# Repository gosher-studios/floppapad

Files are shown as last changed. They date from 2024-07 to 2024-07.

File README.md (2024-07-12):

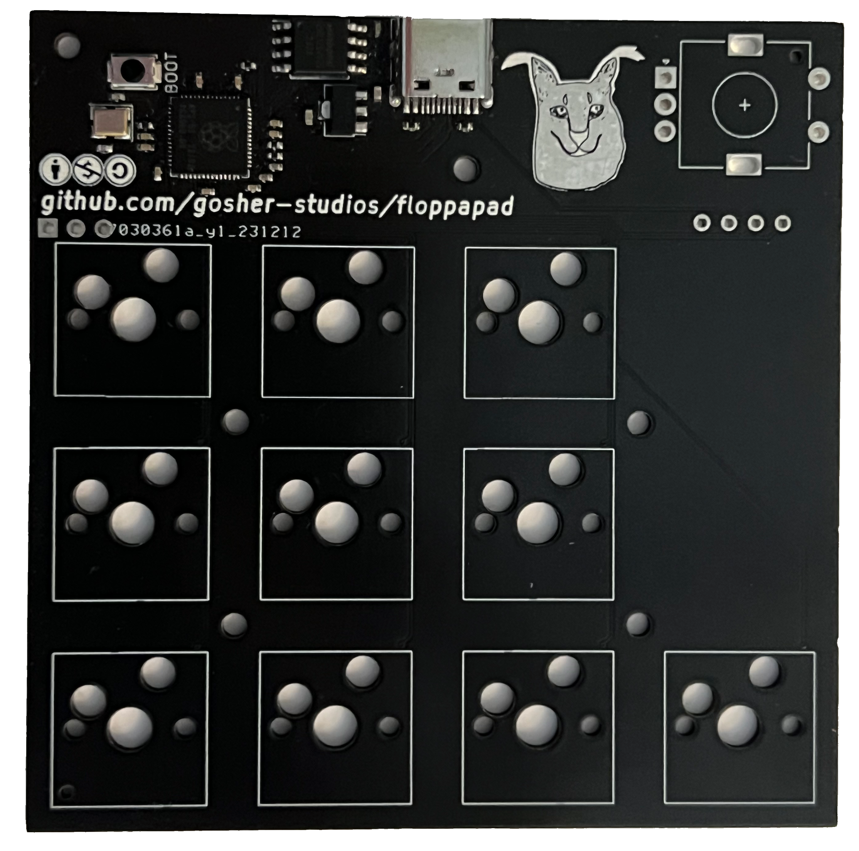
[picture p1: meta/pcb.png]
a black pcb with space for 10 mx switches, rotary encoder, oled display and usb-c port. there is a silver silhouette of a caracal in the top right


floppapad

silly little macropad

### features
- 10 hotswappable mx switches
- 128x32px oled display
- rotary encoder
- usb c
- scriptable and extensible firmware (coming soon)
- the silly caracal
<br/><br/><br/>

### Parts list

| Part | Quantity | Est. price | Example link |
|---|---|---|---|
| RP2040 | 1 | $1.01 | [LCSC](https://www.lcsc.com/product-detail/Microcontroller-Units-MCUs-MPUs-SOCs_Raspberry-Pi-RP2040_C2040.html) |
| USB-C port | 1 | $0.16 | [LCSC](https://www.lcsc.com/product-detail/USB-Connectors_Korean-Hroparts-Elec-TYPE-C-31-M-12_C165948.html) |
| SSD1306 128x32 OLED board | 1 | $4.00 | [42. Keebs](https://42keebs.eu/shop/parts/oled-display-0-91-128x32) |
| EC11 Rotary encoder | 1 | $2.00 | [LCSC](https://www.lcsc.com/product-detail/span-style-background-color-ff0-Rotary-span-Encoders_ALPSALPINE-EC11E183440C_C370986.html) |
| Kailh MX Hotswap sockets | 10 | $3.00 | [Mechboards](https://mechboards.co.uk/collections/components/products/kailh-hotswap-sockets) |
| MX Compatible switches | 10 | ~$10.00 | bring your favourite ✨ |
| SOIC 208-mil SPI flash[^1] | 1 | $0.56 | [LCSC](https://www.lcsc.com/product-detail/NOR-FLASH_Winbond-Elec-W25Q128JVSIQ_C97521.html) |
| SMD3225 12MHz Crystal oscillator | 1 | $0.06 | [LCSC](https://www.lcsc.com/product-detail/Crystals_YXC-X322512MSB4SI_C9002.html) |
| 3.9x2.9mm SMD Switch | 1 | $0.11 | [LCSC](https://www.lcsc.com/product-detail/Tactile-Switches_ALPSALPINE-SKRKAEE020_C115357.html) |
| SOT-89 3.3v Voltage regulator | 1 | $0.05 | [LCSC](https://www.lcsc.com/product-detail/Linear-Voltage-Regulators-LDO_UMW-Youtai-Semiconductor-Co-Ltd-AMS1117-3-3_C347256.html) |
| 27.4Ω Resistors[^2] | 2 | < $0.00 | [LCSC](https://www.lcsc.com/product-detail/Chip-Resistor-Surface-Mount_UNI-ROYAL-Uniroyal-Elec-0402WGF274JTCE_C31439.html) |
| 1kΩ Resistors[^2] | 2 | < $0.00 | [LCSC](https://www.lcsc.com/product-detail/Chip-Resistor-Surface-Mount_UNI-ROYAL-Uniroyal-Elec-0402WGF1001TCE_C11702.html) |
| 5.1kΩ Resistors[^2] | 2 | < $0.00 | [LCSC](https://www.lcsc.com/product-detail/Chip-Resistor-Surface-Mount_UNI-ROYAL-Uniroyal-Elec-0402WGF5101TCE_C25905.html) |
| 27pF Capacitors[^2] | 2 | < $0.00 | [LCSC](https://www.lcsc.com/product-detail/Multilayer-Ceramic-Capacitors-MLCC-SMD-SMT_Samsung-Electro-Mechanics-CL05C270JB51PNC_C472451.html) |
| 100nF Capacitors[^2] | 10 | < $0.00 | [LCSC](https://www.lcsc.com/product-detail/Multilayer-Ceramic-Capacitors-MLCC-SMD-SMT_Samsung-Electro-Mechanics-CL05B104KO5NNNC_C1525.html) |
| 1uF Capacitors[^2] | 2 | < $0.00 | [LCSC](https://www.lcsc.com/product-detail/Multilayer-Ceramic-Capacitors-MLCC-SMD-SMT_Samsung-Electro-Mechanics-CL05A105KA5NQNC_C52923.html) |
| 10uF Capacitors[^2] | 2 | < $0.00 | [LCSC](https://www.lcsc.com/product-detail/Multilayer-Ceramic-Capacitors-MLCC-SMD-SMT_Samsung-Electro-Mechanics-CL05A106MQ5NUNC_C15525.html) |

[^1]: The firmware is ~36KB for a release build. We use 16MB flash.
[^2]: All resistors and capacitors are 0402.

### Credits

Brought to you by Alex T and Gosha T ❤️ \
This work is licensed under [Creative Commons BY-NC-SA 4.0](https://creativecommons.org/licenses/by-nc-sa/4.0/)



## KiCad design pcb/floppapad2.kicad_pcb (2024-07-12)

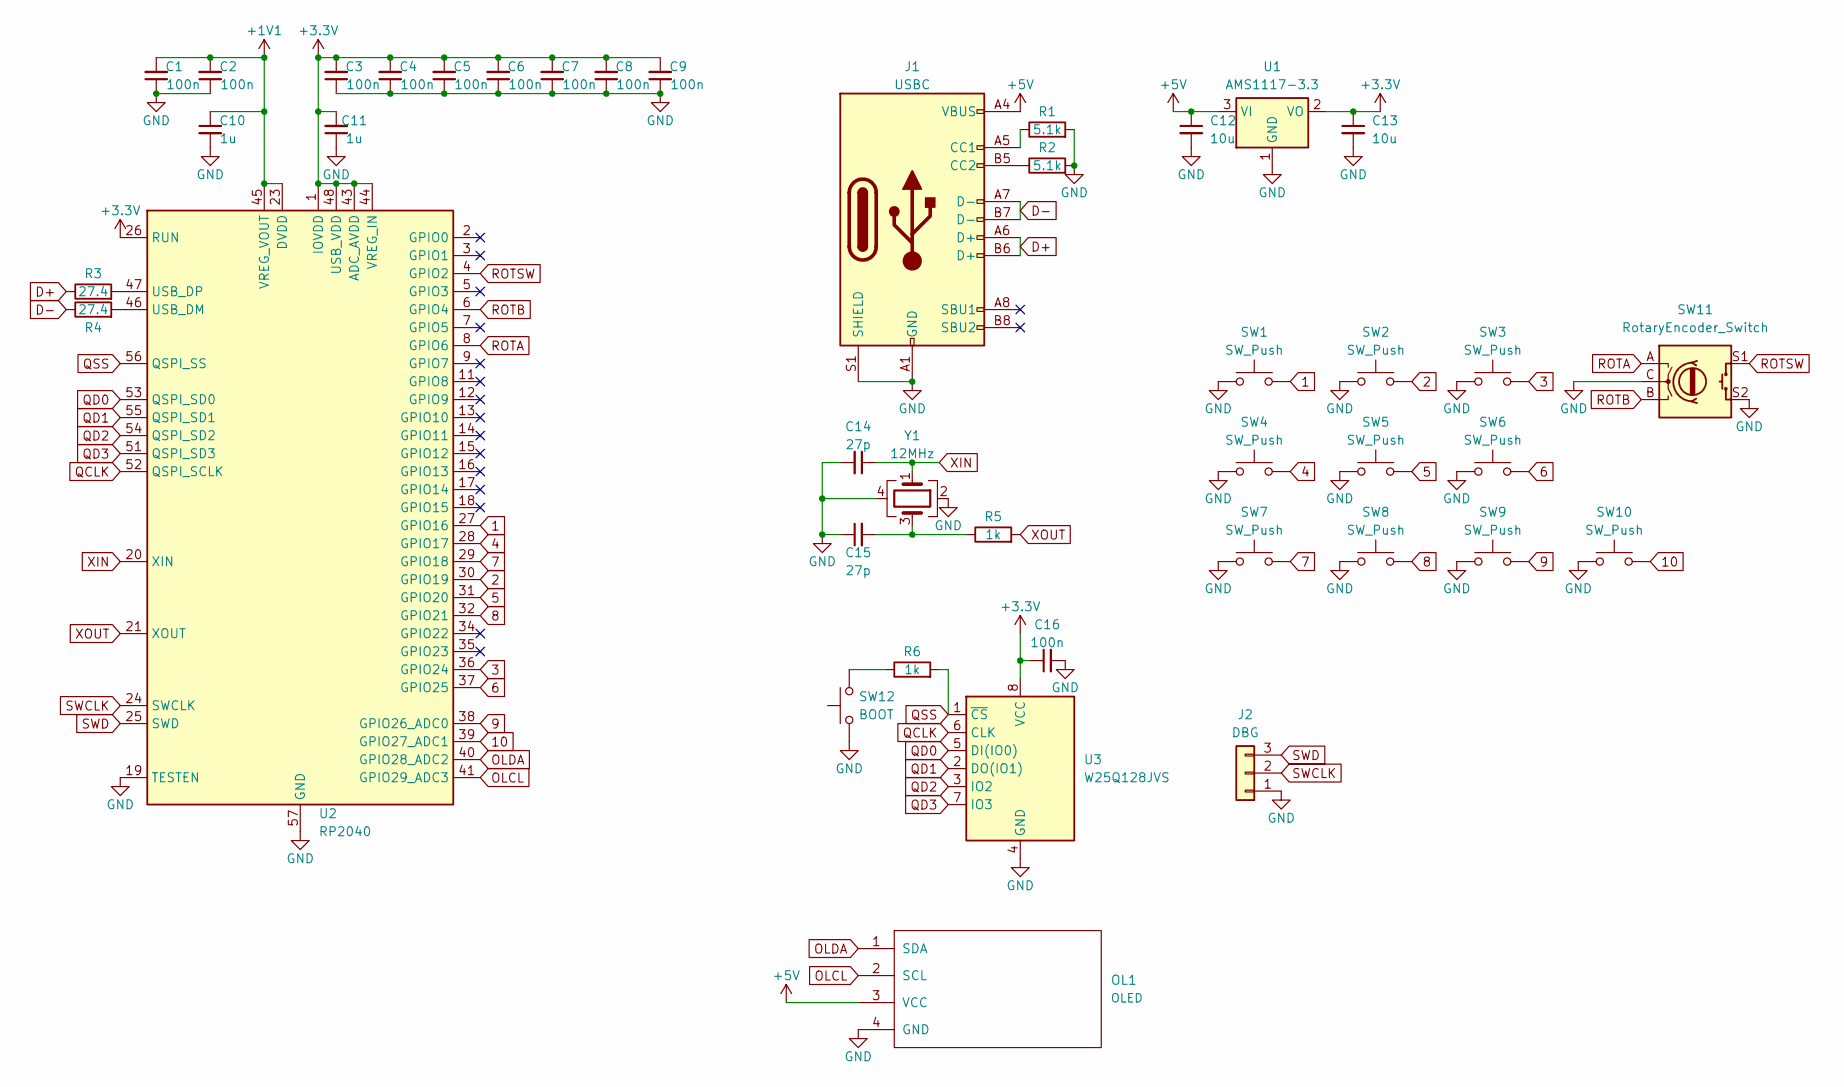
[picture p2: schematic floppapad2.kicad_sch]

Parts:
C1, C2, C3, C4, C5, C6, C7, C8, C9, C16: 100n; C_0402_1005Metric
C10, C11: 1u; C_0402_1005Metric
C12, C13: 10u; C_0402_1005Metric
C14, C15: 27p; C_0402_1005Metric
J1: USBC; USB_C_Receptacle_HRO_TYPE-C-31-M-12
J2: DBG; PinSocket_1x03_P2.54mm_Vertical
OL1: OLED; OLED_v2.1
R1, R2: 5.1k; R_0402_1005Metric
R3, R4: 27.4; R_0402_1005Metric
R5, R6: 1k; R_0402_1005Metric
SW1, SW2, SW3, SW4, SW5, SW6, SW7, SW8, SW9, SW10: SW_Push; SW_Hotswap_Kailh_MX_1.00u
SW11: RotaryEncoder_Switch; RotaryEncoder_Alps_EC11E-Switch_Vertical_H20mm
SW12: BOOT; SW_Push_SPST_NO_Alps_SKRK
U1: AMS1117-3.3; SOT-89-3
U2: RP2040; QFN-56-1EP_7x7mm_P0.4mm_EP3.2x3.2mm
U3: W25Q128JVS; SOIC-8_5.23x5.23mm_P1.27mm
Y1: 12MHz; Crystal_SMD_TXC_7M-4Pin_3.2x2.5mm

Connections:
1: SW1.2, U2.27 (GPIO16)
2: SW2.2, U2.30 (GPIO19)
3: SW3.2, U2.36 (GPIO24)
4: SW4.2, U2.28 (GPIO17)
5: SW5.2, U2.31 (GPIO20)
6: SW6.2, U2.37 (GPIO25)
7: SW7.2, U2.29 (GPIO18)
8: SW8.2, U2.32 (GPIO21)
9: SW9.2, U2.38 (GPIO26_ADC0)
10: SW10.2, U2.39 (GPIO27_ADC1)
+1V1: C1.2, C2.2, C10.1, U2.23 (DVDD), U2.45 (VREG_VOUT), U2.50 (DVDD)
+3.3V: C3.2, C4.2, C5.2, C6.2, C7.2, C8.2, C9.2, C11.2, C13.1, C16.1, U1.2 (VO), U2.1 (IOVDD), U2.10 (IOVDD), U2.22 (IOVDD), U2.26 (RUN), U2.33 (IOVDD), U2.42 (IOVDD), U2.43 (ADC_AVDD), U2.44 (VREG_IN), U2.48 (USB_VDD), U2.49 (IOVDD), U3.8 (VCC)
+5V: C12.1, J1.A4 (VBUS), J1.A9 (VBUS), J1.B4 (VBUS), J1.B9 (VBUS), OL1.3 (VCC), U1.3 (VI)
D+: J1.A6 (D+), J1.B6 (D+), R3.1
D-: J1.A7 (D-), J1.B7 (D-), R4.1
GND: C1.1, C2.1, C3.1, C4.1, C5.1, C6.1, C7.1, C8.1, C9.1, C10.2, C11.1, C12.2, C13.2, C14.2, C15.1, C16.2, J1.A1 (GND), J1.A12 (GND), J1.B1 (GND), J1.B12 (GND), J1.S1 (SHIELD), J2.1, OL1.4 (GND), R1.2, R2.2, SW1.1, SW2.1, SW3.1, SW4.1, SW5.1, SW6.1, SW7.1, SW8.1, SW9.1, SW10.1, SW11.C, SW11.S2, SW12.1, SW12.C, SW12.S2, U1.1 (GND), U2.19 (TESTEN), U2.57 (GND), U3.4 (GND), Y1.2, Y1.4; also elsewhere on the board
unnamed: C15.2, R5.1, Y1.3
unnamed: J1.A5 (CC1), R1.1
unnamed: J1.B5 (CC2), R2.1
unnamed: R6.1, SW12.2
unnamed: R4.2, U2.46 (USB_DM)
unnamed: R3.2, U2.47 (USB_DP)
OLCL: OL1.2 (SCL), U2.41 (GPIO29_ADC3)
OLDA: OL1.1 (SDA), U2.40 (GPIO28_ADC2)
QCLK: U2.52 (QSPI_SCLK), U3.6 (CLK)
QD0: U2.53 (QSPI_SD0), U3.5 (DI(IO0))
QD1: U2.55 (QSPI_SD1), U3.2 (DO(IO1))
QD2: U2.54 (QSPI_SD2), U3.3 (IO2)
QD3: U2.51 (QSPI_SD3), U3.7 (IO3)
QSS: R6.2, U2.56 (QSPI_SS), U3.1 (~CS)
ROTA: SW11.A, U2.8 (GPIO6)
ROTB: SW11.B, U2.6 (GPIO4)
ROTSW: SW11.S1, U2.4 (GPIO2)
SWCLK: J2.2, U2.24 (SWCLK); also elsewhere on the board
SWD: J2.3, U2.25 (SWD); also elsewhere on the board
XIN: C14.1, U2.20 (XIN), Y1.1
XOUT: R5.2, U2.21 (XOUT)

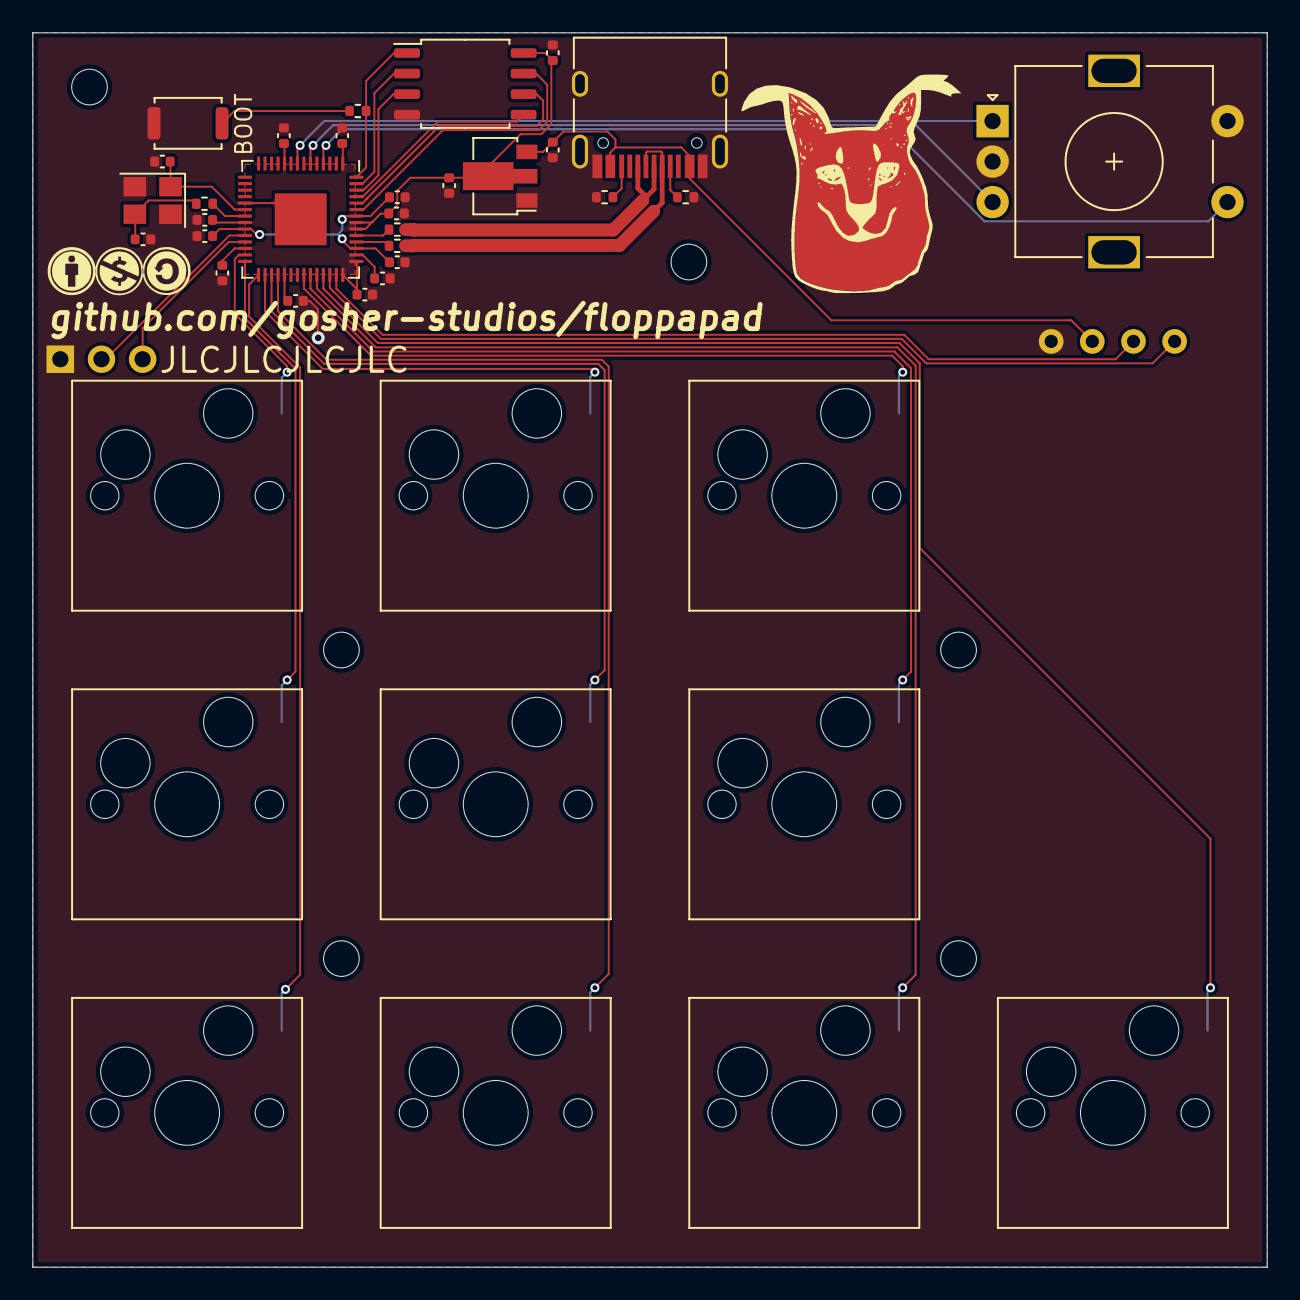
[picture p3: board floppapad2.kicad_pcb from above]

Board: 2 copper layers, 76.2 x 76.2 mm, 41 parts (0 on the bottom side), 37 nets.

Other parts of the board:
DBG: DBG; PinSocket_1x03_P2.54mm_Vertical

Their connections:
GND: DBG.1; also elsewhere on the board
SWCLK: DBG.2; also elsewhere on the board
SWD: DBG.3; also elsewhere on the board

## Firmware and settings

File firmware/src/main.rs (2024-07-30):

#![no_std]
#![no_main]
extern crate alloc;

use core::str;
use core::fmt::Write;
use core::mem::MaybeUninit;
use alloc::string::String;
use alloc::vec::Vec;
use rp2040_hal::pac::Peripherals;
use rp2040_hal::watchdog::Watchdog;
use rp2040_hal::sio::Sio;
use rp2040_hal::clocks::{Clock, init_clocks_and_plls};
use rp2040_hal::timer::Timer;
use rp2040_hal::gpio::{DynPinId, FunctionSioInput, Pin, Pins, PullUp};
use rp2040_hal::i2c::I2C;
use rp2040_hal::usb::UsbBus;
use rp2040_hal::fugit::{ExtU32, RateExtU32};
use rp2040_flash::flash::flash_unique_id;
use cortex_m::interrupt;
use embedded_hal::prelude::*;
use embedded_hal::digital::v2::InputPin;
use embedded_hal::timer::CountDown;
use embedded_alloc::Heap;
use usb_device::{UsbError, UsbDirection, LangID};
use usb_device::bus::{UsbBusAllocator, InterfaceNumber};
use usb_device::device::{UsbDeviceBuilder, UsbVidPid, StringDescriptors};
use usb_device::descriptor::DescriptorWriter;
use usb_device::class::{UsbClass, ControlOut};
use usb_device::endpoint::{EndpointOut, EndpointAddress, EndpointType};
use usb_device::control::RequestType;
use usbd_hid::hid_class::HIDClass;
use usbd_hid::descriptor::{KeyboardReport, KeyboardUsage, SerializedDescriptor};
use ssd1306::{Ssd1306, I2CDisplayInterface};
use ssd1306::size::DisplaySize128x32;
use ssd1306::rotation::DisplayRotation;
use ssd1306::mode::DisplayConfig;
use rhai::{Engine, AST, Scope};
use rhai::packages::{Package, CorePackage};
use defmt::{info, debug, warn};
use floppapad_firmware::{ControlType, VENDOR_ID, VENDOR_NAME, PRODUCT_ID, PRODUCT_NAME, BULK_OUT_ADDR};

use defmt_rtt as _;
use panic_probe as _;

const XOSC_FREQ: u32 = 12_000_000;
const HEAP_SIZE: usize = 1024 * 128;

#[used]
#[link_section = ".boot2"]
static BOOT_LOADER: [u8; 256] = rp2040_boot2::BOOT_LOADER_W25Q080;
#[global_allocator]
static HEAP: Heap = Heap::empty();
static mut HEAP_MEM: [MaybeUninit<u8>; HEAP_SIZE] = [MaybeUninit::uninit(); HEAP_SIZE];

#[rp2040_hal::entry]
unsafe fn main() -> ! {
  info!("floppapad v2, firmware v{}", env!("CARGO_PKG_VERSION"));
  HEAP.init(HEAP_MEM.as_ptr() as _, HEAP_SIZE);
  let mut pac = Peripherals::take().unwrap();
  let mut watchdog = Watchdog::new(pac.WATCHDOG);
  let sio = Sio::new(pac.SIO);
  let clocks = init_clocks_and_plls(
    XOSC_FREQ,
    pac.XOSC,
    pac.CLOCKS,
    pac.PLL_SYS,
    pac.PLL_USB,
    &mut pac.RESETS,
    &mut watchdog,
  )
  .ok()
  .unwrap();
  let timer = Timer::new(pac.TIMER, &mut pac.RESETS, &clocks);

  let usb_bus = UsbBusAllocator::new(UsbBus::new(
    pac.USBCTRL_REGS,
    pac.USBCTRL_DPRAM,
    clocks.usb_clock,
    true,
    &mut pac.RESETS,
  ));
  let mut usb_control = ControlClass::new(&usb_bus);
  let mut usb_hid = HIDClass::new(&usb_bus, KeyboardReport::desc(), 60);
  let serial_number = get_serial_number();
  let version_bcd = get_version_bcd();
  let mut usb_dev = UsbDeviceBuilder::new(&usb_bus, UsbVidPid(VENDOR_ID, PRODUCT_ID))
    .strings(&[StringDescriptors::new(LangID::EN_US)
      .manufacturer(VENDOR_NAME)
      .product(PRODUCT_NAME)
      .serial_number(&serial_number)])
    .unwrap()
    .device_release(version_bcd)
    .build();

  // let pins = Pins::new(
  //   pac.IO_BANK0,
  //   pac.PADS_BANK0,
  //   sio.gpio_bank0,
  //   &mut pac.RESETS,
  // );
  // let mut keys: [Pin<DynPinId, FunctionSioInput, PullUp>; 10] = [
  //   pins.gpio16.into_pull_up_input().into_dyn_pin(), // top left
  //   pins.gpio17.into_pull_up_input().into_dyn_pin(), // middle left
  //   pins.gpio18.into_pull_up_input().into_dyn_pin(), // bottom left
  //   pins.gpio19.into_pull_up_input().into_dyn_pin(), // top middle
  //   pins.gpio20.into_pull_up_input().into_dyn_pin(), // middle middle
  //   pins.gpio21.into_pull_up_input().into_dyn_pin(), // bottom middle
  //   pins.gpio24.into_pull_up_input().into_dyn_pin(), // top right
  //   pins.gpio25.into_pull_up_input().into_dyn_pin(), // middle right
  //   pins.gpio26.into_pull_up_input().into_dyn_pin(), // bottom right
  //   pins.gpio27.into_pull_up_input().into_dyn_pin(), // sigma key TODO rename
  // ];

  // let oled_i2c = I2C::i2c0(
  //   pac.I2C0,
  //   pins.gpio28.into_function(),
  //   pins.gpio29.into_function(),
  //   400.kHz(),
  //   &mut pac.RESETS,
  //   clocks.system_clock.freq(),
  // );
  // let mut oled = Ssd1306::new(
  //   I2CDisplayInterface::new(oled_i2c),
  //   DisplaySize128x32,
  //   DisplayRotation::Rotate0,
  // )
  // .into_terminal_mode();
  // oled.init().unwrap();
  // oled.print_char('f').unwrap();

  let mut engine = Engine::new_raw();
  engine.set_max_strings_interned(1024);
  engine.on_print(|s| info!("rhai: {}", s));
  engine.on_debug(|s, _, _| debug!("rhai: {}", s));
  CorePackage::new().register_into_engine(&mut engine);
  let mut ast = AST::empty();
  let mut scope = Scope::new();

  watchdog.start(1.secs());
  let mut usb_tick = timer.count_down();
  usb_tick.start(1.millis());
  let mut input_tick = timer.count_down();
  input_tick.start(100.millis());
  loop {
    if input_tick.wait().is_ok() {
      match usb_hid.push_input(&KeyboardReport {
        modifier: 0,
        reserved: 0,
        leds: 0,
        // keycodes: [KeyboardUsage::KeyboardAa as _, 0, 0, 0, 0, 0],
        keycodes: [0; 6],
      }) {
        Ok(_) | Err(UsbError::WouldBlock) => {}
        Err(e) => panic!("usb hid error: {:?}", e),
      }
    }
    if usb_tick.wait().is_ok() {
      if usb_dev.poll(&mut [&mut usb_control, &mut usb_hid]) {
        if let Some(src) = usb_control.buf.take_if(|b| b.len() == b.capacity()) {
          match engine.compile(str::from_utf8(&src).unwrap()) {
            Ok(a) => {
              ast = a;
              engine.call_fn::<()>(&mut scope, &ast, "init", ()).unwrap();
            }
            Err(e) => warn!("compile error {}", defmt::Display2Format(&e)),
          }
        }
      }
    }
    watchdog.feed();
  }
}

struct ControlClass<'a> {
  interface: InterfaceNumber,
  bulk_out: EndpointOut<'a, UsbBus>,
  buf: Option<Vec<u8>>,
}

impl<'a> ControlClass<'a> {
  fn new(usb_bus: &'a UsbBusAllocator<UsbBus>) -> Self {
    Self {
      interface: usb_bus.interface(),
      bulk_out: usb_bus
        .alloc(
          Some(EndpointAddress::from_parts(
            BULK_OUT_ADDR as _,
            UsbDirection::Out,
          )),
          EndpointType::Bulk,
          64,
          0,
        )
        .unwrap(),
      buf: None,
    }
  }
}

impl UsbClass<UsbBus> for ControlClass<'_> {
  fn get_configuration_descriptors(&self, writer: &mut DescriptorWriter) -> usb_device::Result<()> {
    writer.interface(self.interface, 0xff, 0, 0)?;
    writer.endpoint(&self.bulk_out)?;
    Ok(())
  }

  fn control_out(&mut self, xfer: ControlOut<UsbBus>) {
    if xfer.request().request_type == RequestType::Vendor {
      match ControlType::from(xfer.request().request) {
        ControlType::PreScript => {
          let len = xfer.request().value;
          self.buf = Some(Vec::with_capacity(len as _));
          debug!("allocated {} for script", len);
          xfer.accept().unwrap();
        }
        ControlType::Test => {
          info!("test");
          xfer.accept().unwrap()
        }
        _ => xfer.reject().unwrap(),
      }
    }
  }

  fn endpoint_out(&mut self, address: EndpointAddress) {
    if self.bulk_out.address() == address {
      if let Some(buf) = &mut self.buf {
        let mut local = [0u8; 64];
        let len = self.bulk_out.read(&mut local).unwrap_or_default();
        if buf.len() + len <= buf.capacity() {
          buf.extend_from_slice(&local[..len]);
        }
        debug!("received {} for script", len);
      }
    }
  }
}

/// generated from flash unique id
fn get_serial_number() -> String {
  let mut buf = [0; 8];
  interrupt::free(|_| unsafe { flash_unique_id(&mut buf, true) });
  let mut str = String::with_capacity(16);
  write!(&mut str, "{:016X}", u64::from_ne_bytes(buf)).unwrap();
  str
}

/// 0xaabc - a is major, b is minor, c is patch
fn get_version_bcd() -> u16 {
  env!("CARGO_PKG_VERSION_MAJOR").parse::<u16>().unwrap() * 0x100
    + env!("CARGO_PKG_VERSION_MINOR").parse::<u16>().unwrap() * 0x10
    + env!("CARGO_PKG_VERSION_PATCH").parse::<u16>().unwrap()
}

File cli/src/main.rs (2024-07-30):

use std::env;
use std::time::Duration;
use rusb::{DeviceHandle, GlobalContext, Direction, RequestType, Recipient};
use owo_colors::OwoColorize;
use floppapad_firmware::{ControlType, BULK_OUT_ADDR, PRODUCT_ID, VENDOR_ID};

const TIMEOUT: Duration = Duration::from_secs(1);

fn main() {
  if let Err(e) = run() {
    println!("{} {}", "error:".red().bold(), e);
  }
}

fn run() -> Result<(), &'static str> {
  match env::args().nth(1).as_deref() {
    Some("info") | Some("i") => {
      let dev = open_dev()?;
      let desc = dev
        .device()
        .device_descriptor()
        .map_err(|_| "could not get device descriptor")?;
      println!(
        "{} {} {}",
        dev
          .read_manufacturer_string_ascii(&desc)
          .map_err(|_| "failed reading strings")?
          .bold(),
        dev
          .read_product_string_ascii(&desc)
          .map_err(|_| "failed reading strings")?
          .bold(),
        format!("({:x}:{:x})", desc.vendor_id(), desc.product_id())
          .bright_white()
          .bold()
      );
      println!(
        "serial: {}",
        dev
          .read_serial_number_string_ascii(&desc)
          .map_err(|_| "failed reading strings")?
          .bright_white()
      );
      println!("firmware version: {}", desc.device_version().bright_white());
    }
    Some("up") => {
      let src = b"fn init() { print(\"meoww\"); }";
      let dev = open_dev()?;
      write_control(&dev, ControlType::PreScript, src.len() as _)?;
      for chunk in src.chunks(64) {
        dev
          .write_bulk(BULK_OUT_ADDR, chunk, TIMEOUT)
          .map_err(|_| "failed writing script")?;
      }
    }
    Some("test") => {
      let dev = open_dev()?;
      write_control(&dev, ControlType::Test, 0)?;
    }
    _ => {
      println!(
        "{}",
        format!("floppapad cli v{}", env!("CARGO_PKG_VERSION")).bold()
      );
      println!("commands:");
      println!("info - {}", "show connected device info".bright_white());
    }
  }
  Ok(())
}

fn write_control(
  dev: &DeviceHandle<GlobalContext>,
  ty: ControlType,
  val: u16,
) -> Result<(), &'static str> {
  dev
    .write_control(
      rusb::request_type(Direction::Out, RequestType::Vendor, Recipient::Interface),
      ty as _,
      val,
      0,
      &[],
      TIMEOUT,
    )
    .map_err(|_| "could not write control request")?;
  Ok(())
}

fn open_dev() -> Result<DeviceHandle<GlobalContext>, &'static str> {
  rusb::open_device_with_vid_pid(VENDOR_ID, PRODUCT_ID).ok_or("could not connect to floppapad")
}

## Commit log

2023-12-11 slight adjustment
    [floppapad2.kicad_pcb, floppapad2.kicad_sch]
2023-12-11 mounting holes
    [floppapad2.kicad_pcb]
2023-12-11 better debug
    [floppapad2.kicad_pcb, floppapad2.kicad_sch]
2023-12-11 exposed copper
    [floppapad2.kicad_pcb]
2023-12-13 i <3 embedded rust
    [floppapad2.kicad_pcb, floppapad2.kicad_sch]

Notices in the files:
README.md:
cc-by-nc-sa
